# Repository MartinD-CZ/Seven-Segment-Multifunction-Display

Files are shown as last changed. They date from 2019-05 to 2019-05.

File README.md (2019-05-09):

# Seven Segment Multifunction Display
*see the article [here](http://embedblog.eu/?p=282)*
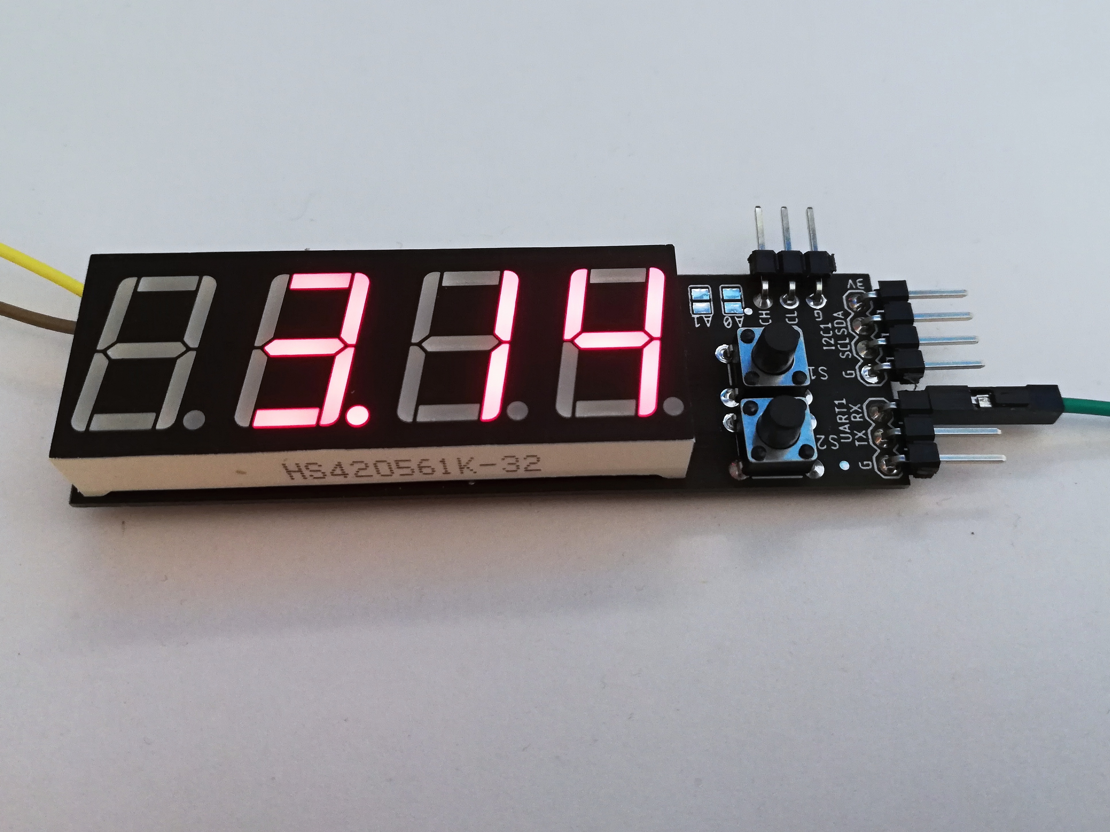
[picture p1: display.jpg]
A picture of the finished display


## Description
A simple project, based on the ATmega88. Can show analog voltage in two ranges (0 - 6 V or 0 - 30 V) with < 1 % accuracy or can display characters sent to it via UART/I2C.

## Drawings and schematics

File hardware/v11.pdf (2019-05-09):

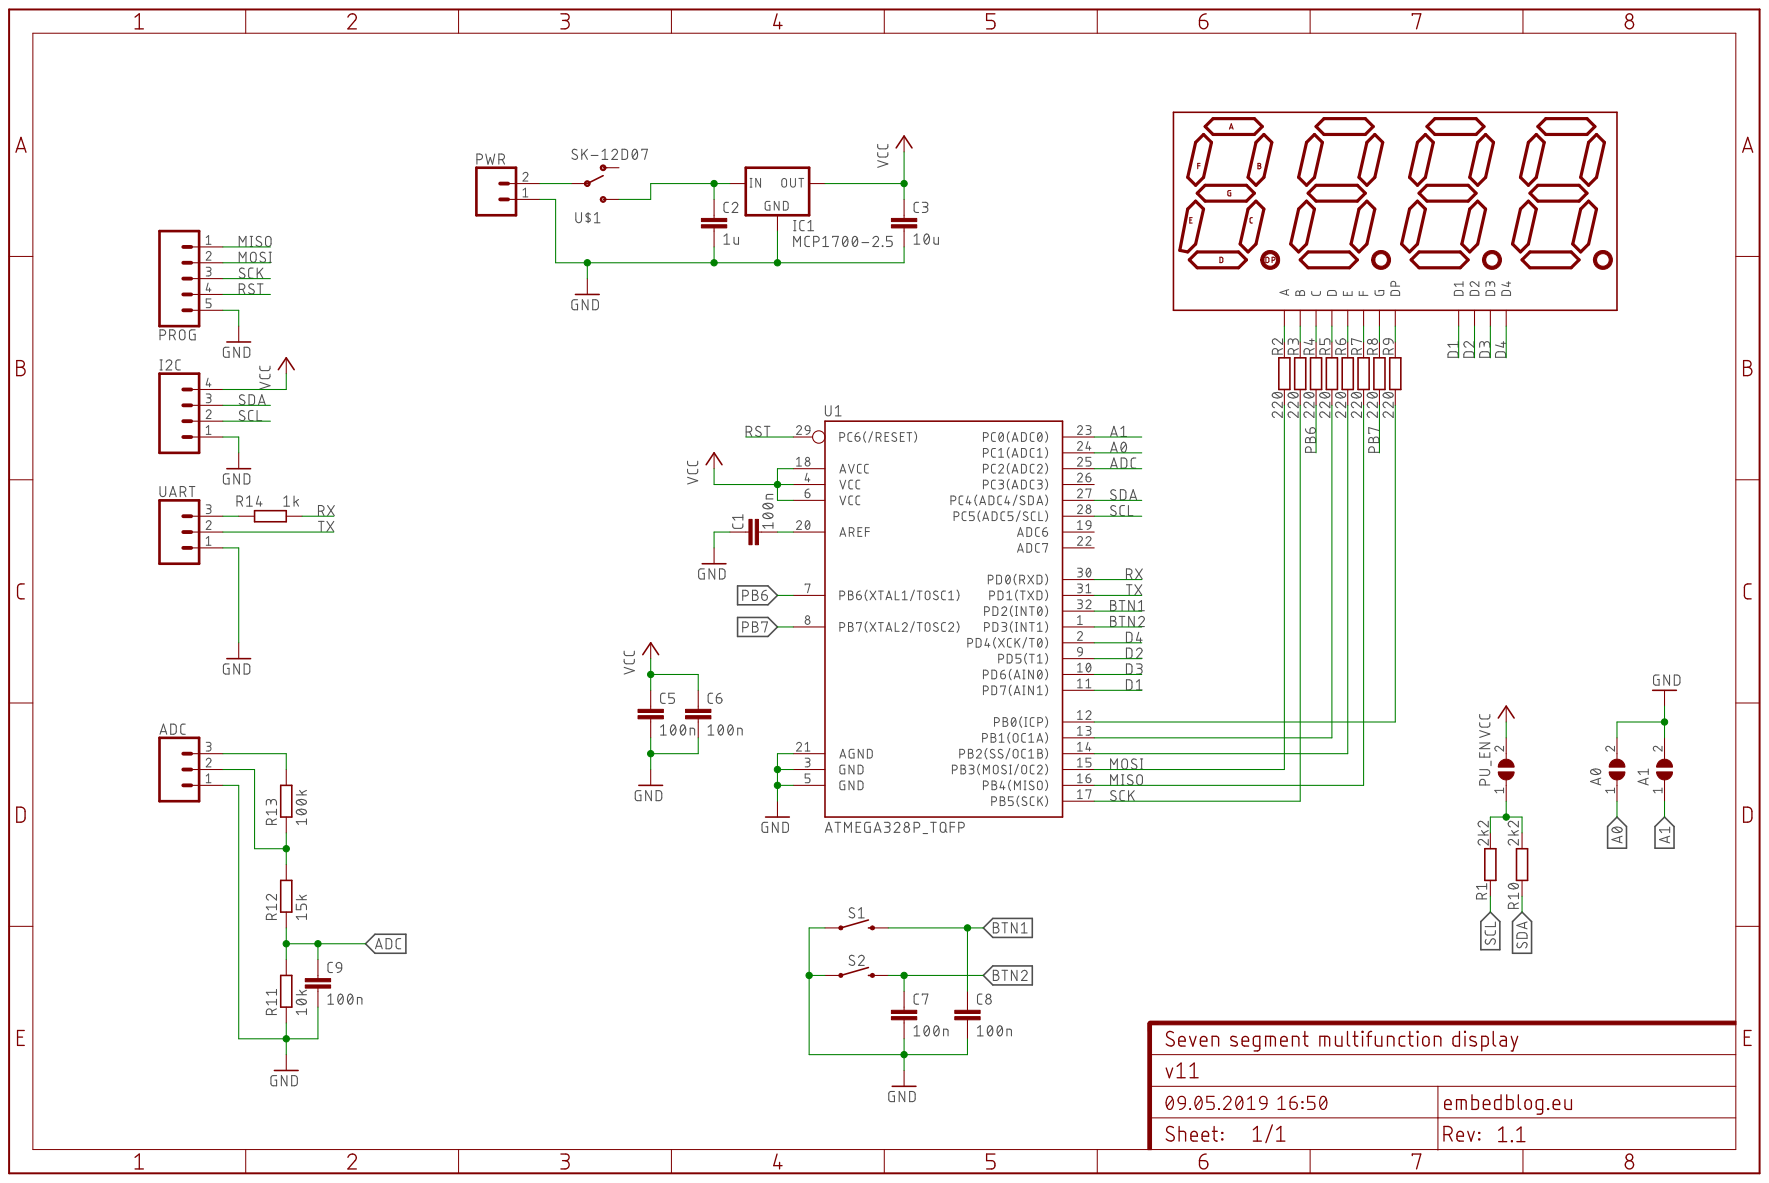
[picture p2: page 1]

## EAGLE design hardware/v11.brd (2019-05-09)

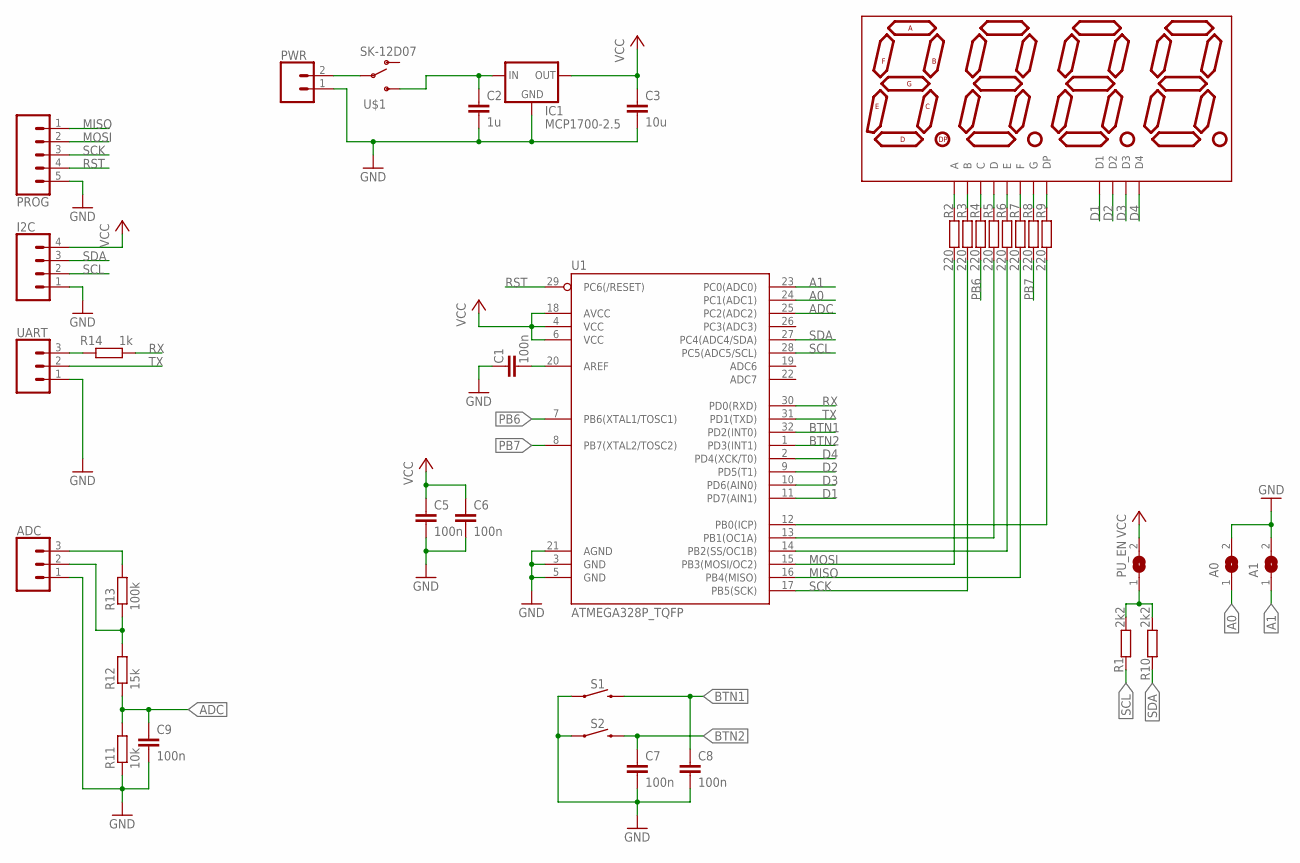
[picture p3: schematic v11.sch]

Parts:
A0, A1: SJ
ADC: 455-1750-1-ND; 1X03
C1, C5, C6, C7, C8, C9: 100n; C1206
C2: 1u; C1206
C3: 10u; C1206
D1: 7-SEG_0.56INCH; 7SEG_0.56INCH
I2C: CONN_04; 1X04
IC1: MCP1700-2.5; SOT23
PROG: CONN_05; 1X05
PU_EN: SJ
PWR: CONN_02; 1X02
R1, R10: 2k2; R1206
R2, R3, R4, R5, R6, R7, R8, R9: 220; R1206
R11: 10k; R1206
R12: 15k; R1206
R13: 100k; R1206
R14: 1k; R1206
S1, S2: MOMENTARY-SWITCH-SPST-PTH-6.0MM; TACTILE_SWITCH_PTH_6.0MM
U1: ATMEGA328P_TQFP; TQFP32-08
U$1: SK-12D07; SK12SWITCH
UART: 455-1750-1-ND; 1X03

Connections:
+3V3: C3.1, C5.1, C6.1, I2C.4, IC1.2 (OUT), PU_EN.2, U1.4 (VCC), U1.6 (VCC), U1.18 (AVCC)
A0: A0.1, U1.24 (PC1(ADC1))
A1: A1.1, U1.23 (PC0(ADC0))
ADC: C9.1, R11.2, R12.1, U1.25 (PC2(ADC2))
BTN1: C8.1, S1.3 (2), U1.32 (PD2(INT0))
BTN2: C7.1, S2.3 (2), U1.1 (PD3(INT1))
D1: D1.D1, U1.11 (PD7(AIN1))
D2: D1.D2, U1.9 (PD5(T1))
D3: D1.D3, U1.10 (PD6(AIN0))
D4: D1.D4, U1.2 (PD4(XCK/T0))
GND: A0.2, A1.2, ADC.1, C1.1, C2.2, C3.2, C5.2, C6.2, C7.2, C8.2, C9.2, I2C.1, IC1.1 (GND), PROG.5, PWR.1, R11.1, S1.1, S2.1, U1.3 (GND), U1.5 (GND), U1.21 (AGND), UART.1
MISO: PROG.1, R7.1, U1.16 (PB4(MISO))
MOSI: PROG.2, R2.1, U1.15 (PB3(MOSI/OC2))
unnamed: PWR.2, U$1.P2
unnamed: C2.1, IC1.3 (IN), U$1.IN (S)
unnamed: PU_EN.1, R1.2, R10.2
unnamed: R14.2, UART.3
unnamed: ADC.3, R13.2
unnamed: ADC.2, R12.2, R13.1
unnamed: D1.A, R2.2
unnamed: D1.B, R3.2
unnamed: D1.C, R4.2
unnamed: D1.D, R5.2
unnamed: D1.E, R6.2
unnamed: D1.F, R7.2
unnamed: D1.G, R8.2
unnamed: D1.DP, R9.2
unnamed: C1.2, U1.20 (AREF)
unnamed: R6.1, U1.14 (PB2(SS/OC1B))
unnamed: R5.1, U1.13 (PB1(OC1A))
unnamed: R9.1, U1.12 (PB0(ICP))
PB6: R4.1, U1.7 (PB6(XTAL1/TOSC1))
PB7: R8.1, U1.8 (PB7(XTAL2/TOSC2))
RST: PROG.4, U1.29 (PC6(/RESET))
RX: R14.1, U1.30 (PD0(RXD))
SCK: PROG.3, R3.1, U1.17 (PB5(SCK))
SCL: I2C.2, R1.1, U1.28 (PC5(ADC5/SCL))
SDA: I2C.3, R10.1, U1.27 (PC4(ADC4/SDA))
TX: U1.31 (PD1(TXD)), UART.2

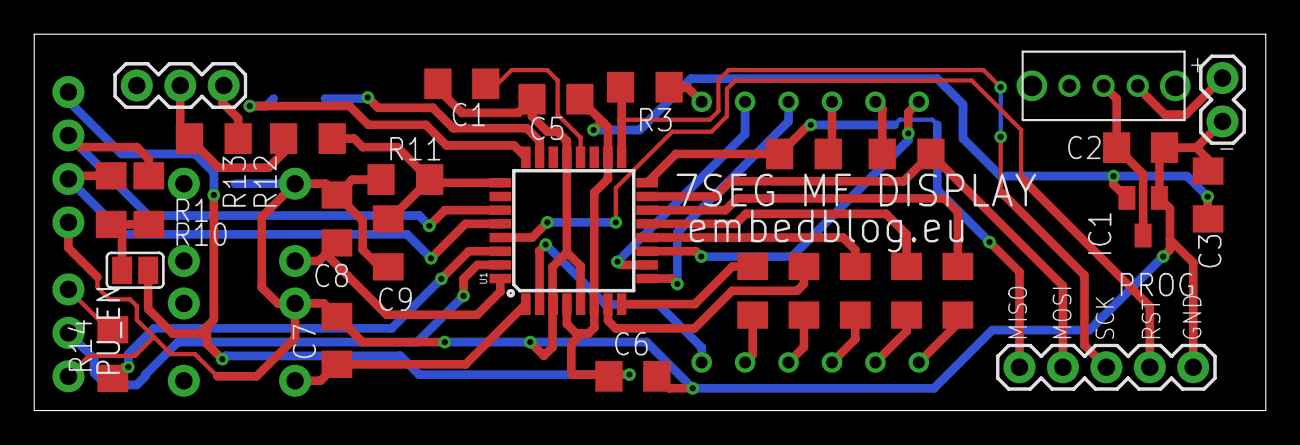
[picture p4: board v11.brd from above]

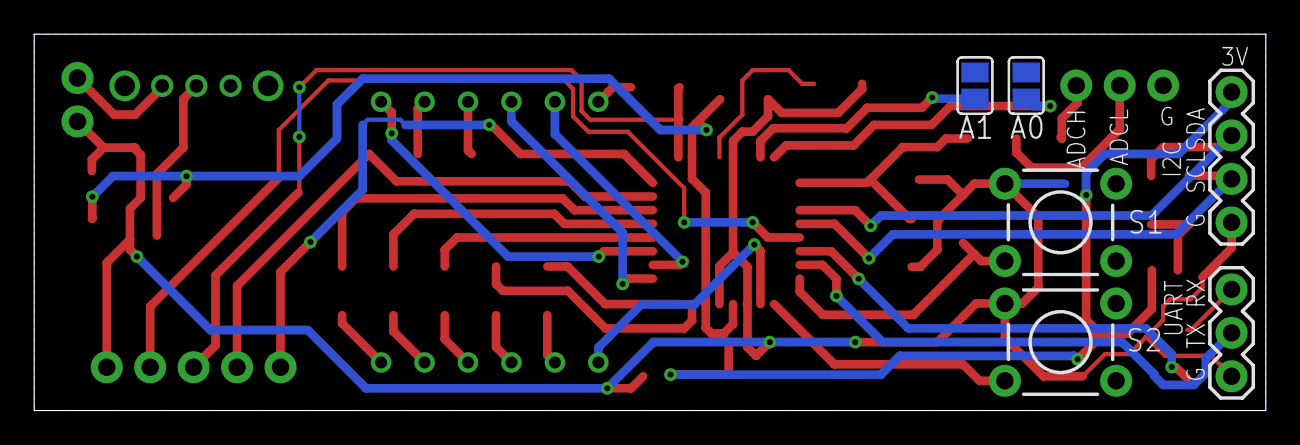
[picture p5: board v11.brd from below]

Board: 2 copper layers, 72.0 x 22.0 mm, 36 parts (7 on the bottom side), 39 nets.

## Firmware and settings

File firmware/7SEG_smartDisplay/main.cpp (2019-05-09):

/*
 * 7SEG_smartDisplay.cpp
 * SEVEN SEGMENT MULTIFUNCTION DISPLAY	
 *
 * Author: martin@embedblog.eu
 * http://embedblog.eu/?p=282
 */ 

#include <avr/io.h>
#include "defines.h"
#include <util/delay.h>
#include <avr/interrupt.h>
#include "adc.h"
#include "uart.h"
#include "i2c.h"

const static float ADCL_GAIN = (R11_VALUE + R12_VALUE) / R11_VALUE;
const static float ADCH_GAIN = (R11_VALUE + R12_VALUE + R13_VALUE) / (10 * R11_VALUE);

volatile uint8_t display_digits[4];
volatile uint8_t display_pos;
volatile uint8_t decimal_pos;	//four LSBs correspond to the DPs

volatile uint8_t mode;
volatile bool mode_changed = true;
volatile bool hold;
volatile bool s1_pressed;

extern volatile uint8_t uart_output[4];
extern volatile uint8_t uart_outputDecimal;

extern volatile uint8_t i2c_output[4];
extern volatile uint8_t i2c_outputDecimal;

volatile uint8_t counter_25ms;

int main(void)
{
    //GPIO setup
	DDRB = 0xFF;
	DDRD = (1 << DDD4) | (1 << DDD5) | (1 << DDD6) | (1 << DDD7);

	//ADC setup
	adc_init();

	//UART setup
	uart_init();

	//I2C setup
	i2c_init();

	//INT setup
	PORTD = (1 << PD2) | (1 << PD3);
	EICRA = (1 << ISC11) | (1 << ISC01);
	EIMSK = (1 << INT1) | (1 << INT0);
	
	//TIMER0 setup - used to multiplex the display at around 500 Hz
	TCCR0B = (1 << CS00) | (1 << CS01);
	TIMSK0 = (1 << TOIE0);

	//TIMER2 setup - used to keep time (interrupt every 25 ms)
	TCCR2B = (1 << WGM21) | (1 << CS20) | (1 << CS21) | (1 << CS22);
	OCR2A = 195;
	TIMSK2 = (1 << OCIE2A);

	sei();

    while (1) 
    {
		uint16_t adc_result = adc_getResult();
		switch (mode)
		{
			case MODE_ADCL:
			{
				if (mode_changed)
				{
					decimal_pos = 0x00;
					mode_changed = false;
					SET_DISPLAY(CHAR_A, CHAR_D, CHAR_C, CHAR_L);
					_delay_ms(TRANSITION_TIME);
				}
				
				decimal_pos = 0b1000;
				adc_result *= ADCL_GAIN;
				for (int8_t i = 3; i >= 0; i --)
				{
					display_digits[i] = adc_result % 10;
					adc_result /= 10;
				}

				while (hold);
				break;
			}
			case MODE_ADCH:
			{
				if (mode_changed)
				{
					decimal_pos = 0x00;
					mode_changed = false;
					SET_DISPLAY(CHAR_A, CHAR_D, CHAR_C, CHAR_H);
					_delay_ms(TRANSITION_TIME);
				}
				
				decimal_pos = 0b0100;
				adc_result *= ADCH_GAIN;
				for (int8_t i = 3; i >= 0; i --)
				{
					display_digits[i] = adc_result % 10;
					adc_result /= 10;
				}

				while (hold);
				break;
			}
			case MODE_UART:
			{
				if (mode_changed)
				{
					decimal_pos = 0x00;
					mode_changed = false;
					SET_DISPLAY(CHAR_U, CHAR_A, CHAR_R, CHAR_T);
					_delay_ms(TRANSITION_TIME);
				}

				if (s1_pressed)
				{
					s1_pressed = false;
					decimal_pos = 0b0010;
					switch (uart_changeBaud())
					{
						case 0: {SET_DISPLAY(CHAR_BLANK, CHAR_BLANK, 9, 6); break;}
						case 1: {SET_DISPLAY(CHAR_BLANK, 1, 9, 2); break;}
						case 2: {SET_DISPLAY(CHAR_BLANK, 3, 8, 4); break;}
						case 3: {SET_DISPLAY(CHAR_BLANK, 5, 7, 6); break;}
						case 4: {SET_DISPLAY(1, 1, 5, 2); break;}
						case 5: {SET_DISPLAY(1, 0, 0, 0); decimal_pos = 0x00; break;}
					}

					_delay_ms(TRANSITION_TIME);
				}

				decimal_pos = uart_outputDecimal;
				SET_DISPLAY(uart_output[0], uart_output[1], uart_output[2], uart_output[3]);
				break;
			}
			case MODE_I2C:
			{
				if (mode_changed)
				{
					decimal_pos = 0x00;
					mode_changed = false;
					SET_DISPLAY(CHAR_BLANK, CHAR_I, 2, CHAR_C);
					_delay_ms(TRANSITION_TIME);
				}
				
				decimal_pos = i2c_outputDecimal;
				SET_DISPLAY(i2c_output[0], i2c_output[1], i2c_output[2], i2c_output[3]);
				break;
			}
		}

		_delay_ms(1000 / REFRESH_RATE);
    }
}

//timer 0 - used to multiplex the display
ISR(TIMER0_OVF_vect)
{
	display_pos++;
	if (display_pos > 3)
		display_pos = 0;

	PORTD |= 0b11110000;
	switch (display_pos)
	{
		case 0:
		{
			PORTB = charMap[display_digits[0]];
			if ((decimal_pos >> 3) & 0x01)
				PORTB |= 0x01;
			PORTD &=~(1 << PD7);
			break;
		}
		case 1:
		{
			PORTB = charMap[display_digits[1]];
			if ((decimal_pos >> 2) & 0x01)
				PORTB |= 0x01;
			PORTD &=~(1 << PD5);
			break;
		}
		case 2:
		{
			PORTB = charMap[display_digits[2]];
			if ((decimal_pos >> 1) & 0x01)
				PORTB |= 0x01;
			PORTD &=~(1 << PD6);
			break;
		}
		case 3:
		{
			PORTB = charMap[display_digits[3]];
			if (decimal_pos & 0x01)
				PORTB |= 0x01;
			PORTD &=~(1 << PD4);
			break;
		}
	}
}

//interrupt every 25 ms
ISR(TIMER2_COMPA_vect)
{
	counter_25ms++;
}

//button S1
ISR(INT0_vect)
{
	hold = !hold;
	s1_pressed = true;
}

//button S2
ISR(INT1_vect)
{
	mode_changed = true;
	mode++;
	if (mode >= MODES_NUMBER)
		mode = 0;
}

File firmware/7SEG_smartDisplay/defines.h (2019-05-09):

/*
 * defines.h
 * SEVEN SEGMENT MULTIFUNCTION DISPLAY
 *
 * Author: martin@embedblog.eu
 * http://embedblog.eu/?p=282
 */


#ifndef DEFINES_H_
#define DEFINES_H_

//======================================================
//USER SETTINGS

#define REFRESH_RATE		5				//in Hz
#define TRANSITION_TIME		1200			//how long (in ms) a transistion message is shown

#define R11_VALUE			9.993			//resistance (in kohms)
#define R12_VALUE			14.931
#define R13_VALUE			99.97
#define VIN					2504

#define I2C_ADDRESS			0b010100		//default I2C address

//END OF SETTINGS
//======================================================

#define F_CPU 8000000UL

const uint8_t charMap[] = {
	0x7E,		//0
	0x60,		//1
	0xAE,		//2
	0xEA,		//3
	0xF0,		//4
	0xDA,		//5
	0xDE,		//6
	0x68,		//7
	0xFE,		//8
	0xFA,		//9
	0xFC,		//CHAR_A
	0xE6,		//CHAR_D
	0x86,		//CHAR_C
	0x16,		//CHAR_L
	0xF4,		//CHAR_H
	0x76,		//CHAR_U
	0x96,		//CHAR_T
	0x84,		//CHAR_R
	0x00,		//CHAR_BLANK
	0x80,		//CHAR_DASH
	0x02,		//CHAR_UNDERSCORE
	0x40		//CHAR_I
};

#define CHAR_A			10
#define CHAR_D			11
#define CHAR_C			12
#define CHAR_L			13
#define CHAR_H			14
#define CHAR_U			15
#define CHAR_T			16
#define CHAR_R			17
#define CHAR_BLANK		18
#define CHAR_DASH		19
#define CHAR_UNDERSCORE	20
#define CHAR_I			21

#define MODE_ADCL		0
#define MODE_ADCH		1
#define MODE_UART		2
#define MODE_I2C		3

#define MODES_NUMBER	4

#define SET_DISPLAY(x, y, z, a)		display_digits[0] = x; display_digits[1] = y; display_digits[2] = z; display_digits[3] = a

#endif /* DEFINES_H_ */

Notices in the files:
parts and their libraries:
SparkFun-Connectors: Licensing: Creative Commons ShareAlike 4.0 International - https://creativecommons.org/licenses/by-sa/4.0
